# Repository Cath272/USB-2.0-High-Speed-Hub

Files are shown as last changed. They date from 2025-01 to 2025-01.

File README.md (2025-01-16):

# USB-2.0-High-Speed-Hub
USB 2.0 High Speed Hub with MicroSD card slot PCB designed with Kicad 8.0

Kicad Project Files, Gerber Files and STL for the case can be found in the project folders
Case uses M2X6 Screws 

# ICs

### CH334

  - USB2.0 protocol compliant 4-port USB HUB controller chip

  - Uses a 12MHz Crystal

  - 0603 100mA Fuse for limiting power to ic

  - Internal 5V to 3.3V LDO

  - Activity LED

  - [Datasheet](https://www.wch-ic.com/downloads/CH334DS1_PDF.html)

### GL823K 

  - USB 2.0 SD/MSPRO Card Reader Controller

  - Internal 5V to 3.3V LDO, can self power microSD card

  - Activity LED
  
  - [Datasheet](https://www.lcsc.com/datasheet/lcsc_datasheet_2409272232_Genesys-Logic-GL823K-HCY04_C284879.pdf)

### CH213K
  - 0.5A Low dropout ideal diode chip with current limiting function 

  - [Datasheet](https://www.wch-ic.com/downloads/CH213DS1_PDF.html)

### USBLC6
- Very low capacitance ESD protection for USB data lines

- [Datasheet](https://www.st.com/resource/en/datasheet/usblc6-2.pdf)

# Ports

### UPSTREAM

- 1 USB Type C Upstream Port (16P SMD PORT)

### DOWNSTREAM

- 2 USB TYPE C Downstream Ports (16P SMD PORT)

- 1 USB Type A Downstream Port (AF10.0 USB A, the footprint is wrong so i bent the front legs when I assambled it, to be changed) 

- 1 MicroSD card Slot (Common style size 14*15mm)

USB C ports are USB PD compliant

# Schematic

USB 2 0 High Speed Hub

# PCB

FRONT:

usb2front

BACK:

usb2back

3D:

usb2front3d
usb2back3d

# Photos










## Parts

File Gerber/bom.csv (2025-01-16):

Designator | Footprint | Quantity | Value | LCSC Part #
C1, C10, C7 | 0603 | 3 | 0.1u
C2, C8, C9 | 0805 | 3 | 10u
C3 | 0805 | 1 | 1u
C4, C5, C6 | CP_EIA-3528-15_AVX-H_Pad1.50x2.35mm_HandSolder | 3 | 100uF
D1, D2 | 0603 | 2 | LED
F1 | 0603 | 1 | 100mA Fuse
J2, J3, J6 | USB_C_Receptacle_GCT_USB4105-xx-A_16P_TopMnt_Horizontal | 3 | USB_C_Receptacle_USB2.0_16P
J4 | USB-A-SMD_11.0180CB1.9 | 1 | USB_A
J5 | SUNTECH_ST-TF-003A | 1 | Micro_SD_Card
R1, R2 | 0402 | 2 | 5.1k
R3, R8 | 0402 | 2 | 1k
R4, R5, R6, R7 | 0402 | 4 | 22K
U1 | QFN-16_L3.0-W3.0-P0.50-BL-EP1.7 | 1 | CH334P | C5373042
U2 | SOT-23 | 1 | CH213K
U3, U4, U6, U7 | SOT-23-6 | 4 | USBLC6-2SC6
U8 | SSOP-16_L4.9-W3.9-P0.64-LS6.0-BL | 1 | GL823K-HCY04 | C284879
Y1 | Crystal_SMD_3225-4Pin_3.2x2.5mm | 1 | Crystal 12MHz

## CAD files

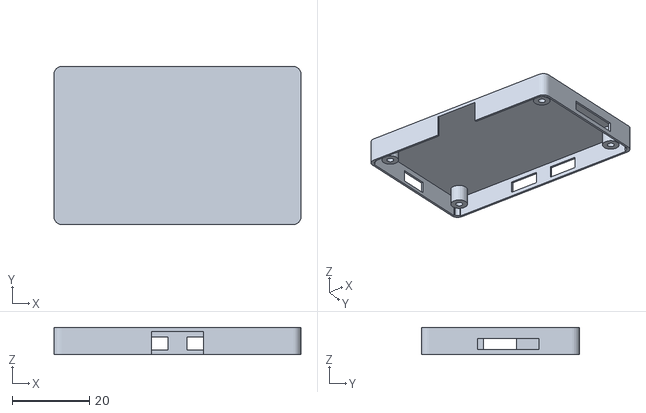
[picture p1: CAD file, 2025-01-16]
Case/usbhubfront_3d.stl
64.0 x 41.0 x 7.00

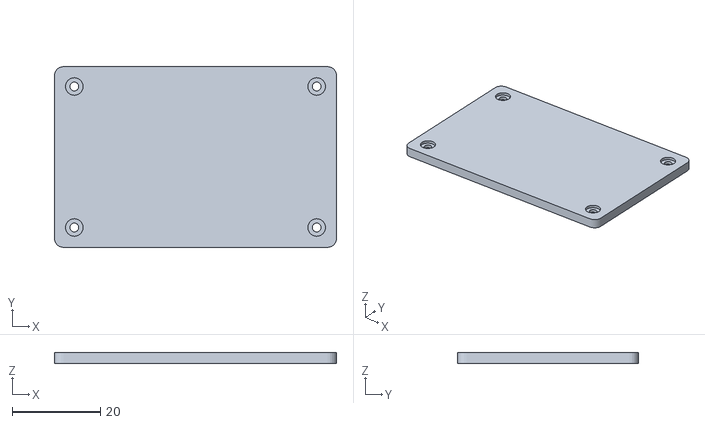
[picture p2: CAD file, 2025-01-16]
Case/usbhubback_3d.stl
64.0 x 41.0 x 2.50

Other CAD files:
Case/usbhubback_3d.dwg
Case/usbhubfront_3d.dwg

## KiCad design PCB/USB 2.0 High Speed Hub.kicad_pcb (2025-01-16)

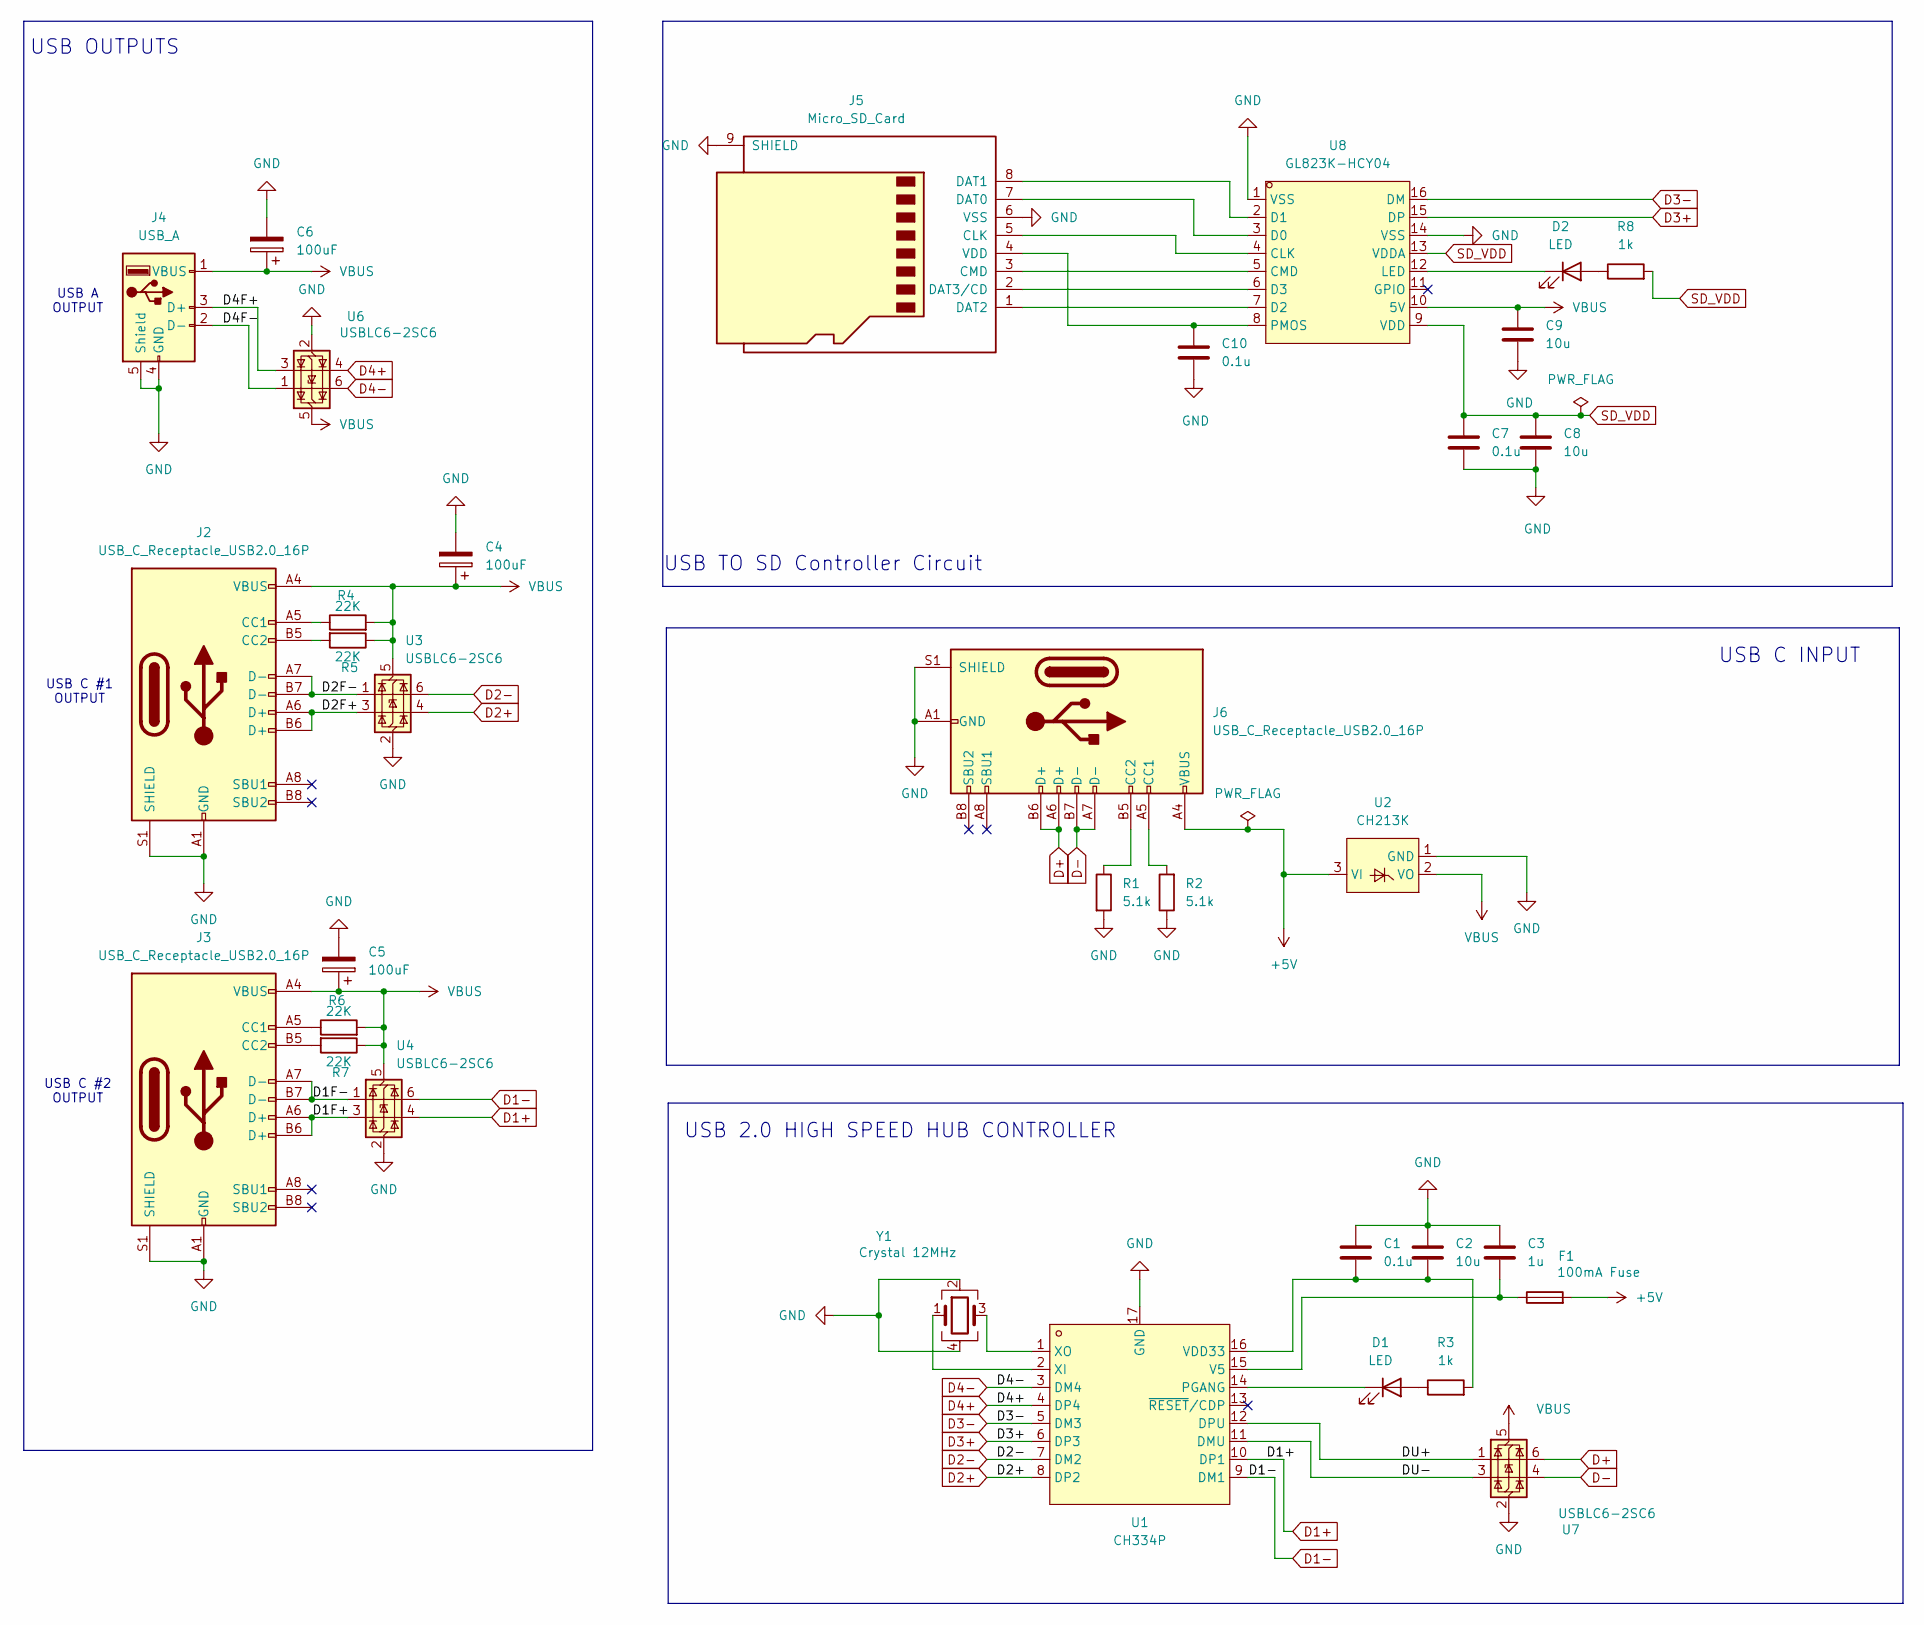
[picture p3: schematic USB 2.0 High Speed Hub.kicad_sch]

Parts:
C1, C7, C10: 0.1u; C_0603_1608Metric_Pad1.08x0.95mm_HandSolder
C2, C8, C9: 10u; C_0805_2012Metric_Pad1.18x1.45mm_HandSolder
C3: 1u; C_0805_2012Metric_Pad1.18x1.45mm_HandSolder
C4, C5, C6: 100uF; CP_EIA-3528-15_AVX-H_Pad1.50x2.35mm_HandSolder
D1, D2: LED; LED_0603_1608Metric_Pad1.05x0.95mm_HandSolder
F1: 100mA Fuse; Fuse_0603_1608Metric_Pad1.05x0.95mm_HandSolder
J2, J3, J6: USB_C_Receptacle_USB2.0_16P; USB_C_Receptacle_GCT_USB4105-xx-A_16P_TopMnt_Horizontal
J4: USB_A; USB-A-SMD_11.0180CB1.9
J5: Micro_SD_Card; SUNTECH_ST-TF-003A
R1, R2: 5.1k; R_0402_1005Metric_Pad0.72x0.64mm_HandSolder
R3, R8: 1k; R_0402_1005Metric_Pad0.72x0.64mm_HandSolder
R4, R5, R6, R7: 22K; R_0402_1005Metric_Pad0.72x0.64mm_HandSolder
U1: CH334P; QFN-16_L3.0-W3.0-P0.50-BL-EP1.7; LCSC Part C5373042
U2: CH213K; SOT-23
U3, U4, U6, U7: USBLC6-2SC6; SOT-23-6
U8: GL823K-HCY04; SSOP-16_L4.9-W3.9-P0.64-LS6.0-BL; LCSC Part C284879
Y1: Crystal 12MHz; Crystal_SMD_3225-4Pin_3.2x2.5mm

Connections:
+5V: F1.2, J6.A4 (VBUS), J6.A9 (VBUS), J6.B4 (VBUS), J6.B9 (VBUS), U2.3 (VI)
/D1F+: J3.A6 (D+), J3.B6 (D+), U4.3 (I/O2)
/D1F-: J3.A7 (D-), J3.B7 (D-), U4.1 (I/O1)
/D2F+: J2.A6 (D+), J2.B6 (D+), U3.3 (I/O2)
/D2F-: J2.A7 (D-), J2.B7 (D-), U3.1 (I/O1)
/D4F+: J4.3 (D+), U6.3 (I/O2)
/D4F-: J4.2 (D-), U6.1 (I/O1)
/DU+: U1.12 (DPU), U7.1 (I/O1)
/DU-: U1.11 (DMU), U7.3 (I/O2)
D1+: U1.10 (DP1), U4.4 (I/O2)
D1-: U1.9 (DM1), U4.6 (I/O1)
D2+: U1.8 (DP2), U3.4 (I/O2)
D2-: U1.7 (DM2), U3.6 (I/O1)
D3+: U1.6 (DP3), U8.15 (DP)
D3-: U1.5 (DM3), U8.16 (DM)
D4+: U1.4 (DP4), U6.4 (I/O2)
D4-: U1.3 (DM4), U6.6 (I/O1)
D+: J6.A6 (D+), J6.B6 (D+), U7.6 (I/O1)
D-: J6.A7 (D-), J6.B7 (D-), U7.4 (I/O2)
GND: C1.1, C2.1, C3.1, C4.2, C5.2, C6.2, C7.2, C8.2, C9.2, C10.2, J2.A1 (GND), J2.A12 (GND), J2.B1 (GND), J2.B12 (GND), J2.S1 (SHIELD), J3.A1 (GND), J3.A12 (GND), J3.B1 (GND), J3.B12 (GND), J3.S1 (SHIELD), J4.4 (GND), J4.5 (Shield), J5.6 (VSS), J5.9 (SHIELD), J6.A1 (GND), J6.A12 (GND), J6.B1 (GND), J6.B12 (GND), J6.S1 (SHIELD), R1.2, R2.1, U1.17 (GND), U2.1 (GND), U3.2 (GND), U4.2 (GND), U6.2 (GND), U7.2 (GND), U8.1 (VSS), U8.14 (VSS), Y1.2, Y1.4
unnamed: D1.2 (A), R3.1
unnamed: D1.1 (K), U1.14 (PGANG)
unnamed: D2.2 (A), R8.1
unnamed: D2.1 (K), U8.12 (LED)
unnamed: J2.A5 (CC1), R4.1
unnamed: J2.B5 (CC2), R5.2
unnamed: J3.A5 (CC1), R6.1
unnamed: J3.B5 (CC2), R7.2
unnamed: J5.5 (CLK), U8.4 (CLK)
unnamed: J5.3 (CMD), U8.5 (CMD)
unnamed: J5.7 (DAT0), U8.3 (D0)
unnamed: J5.8 (DAT1), U8.2 (D1)
unnamed: J5.1 (DAT2), U8.7 (D2)
unnamed: J5.2 (DAT3/CD), U8.6 (D3)
unnamed: C10.1, J5.4 (VDD), U8.8 (PMOS)
unnamed: J6.A5 (CC1), R2.2
unnamed: J6.B5 (CC2), R1.1
unnamed: C3.2, F1.1, U1.15 (V5)
unnamed: C1.2, C2.2, R3.2, U1.16 (VDD33)
unnamed: U1.2 (XI), Y1.1
unnamed: U1.1 (XO), Y1.3
SD_VDD: C7.1, C8.1, R8.2, U8.9 (VDD), U8.13 (VDDA)
VBUS: C4.1, C5.1, C6.1, C9.1, J2.A4 (VBUS), J2.A9 (VBUS), J2.B4 (VBUS), J2.B9 (VBUS), J3.A4 (VBUS), J3.A9 (VBUS), J3.B4 (VBUS), J3.B9 (VBUS), J4.1 (VBUS), R4.2, R5.1, R6.2, R7.1, U2.2 (VO), U3.5 (VBUS), U4.5 (VBUS), U6.5 (VBUS), U7.5 (VBUS), U8.10 (5V)

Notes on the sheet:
USB OUTPUTS
USB C INPUT
USB C #2 OUTPUT
USB A OUTPUT
USB C #1 OUTPUT
USB TO SD Controller Circuit
USB 2.0 HIGH SPEED HUB CONTROLLER

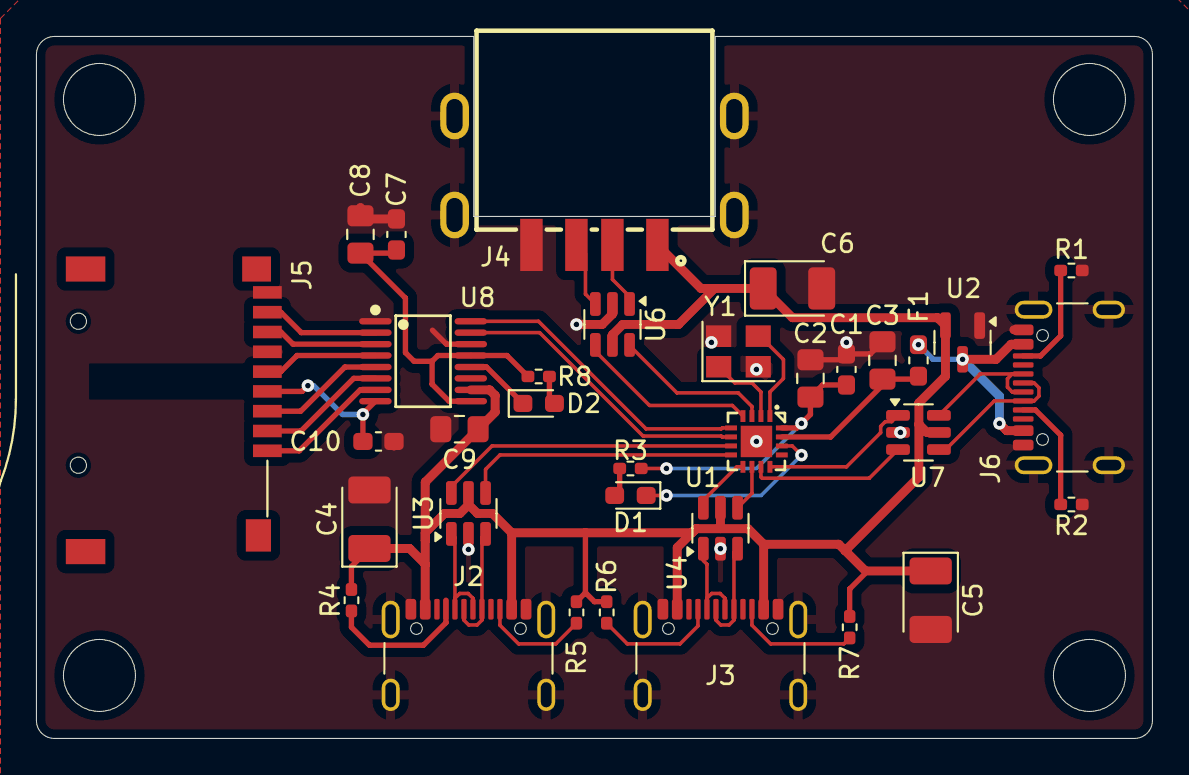
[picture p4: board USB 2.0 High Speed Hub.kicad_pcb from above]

Board: 2 copper layers, 62.0 x 39.0 mm, 34 parts (0 on the bottom side), 43 nets.
